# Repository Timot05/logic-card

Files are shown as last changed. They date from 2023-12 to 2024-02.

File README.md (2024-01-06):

# A kit to learn about logic gates

*written in `ato`*

The enclosure contains a programmable microcontroller, two buttons and an LED. Cards can be plugged on top of the enclosure. They turn on the device and program the buttons to act in the same way described by the card placed on the enclosure.

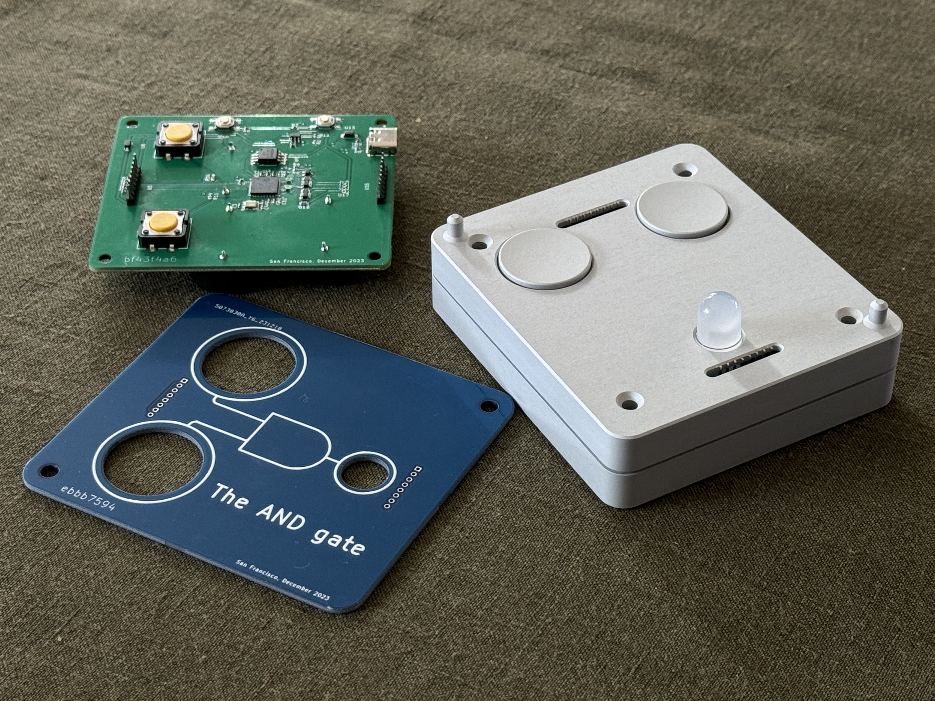
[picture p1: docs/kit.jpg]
gates


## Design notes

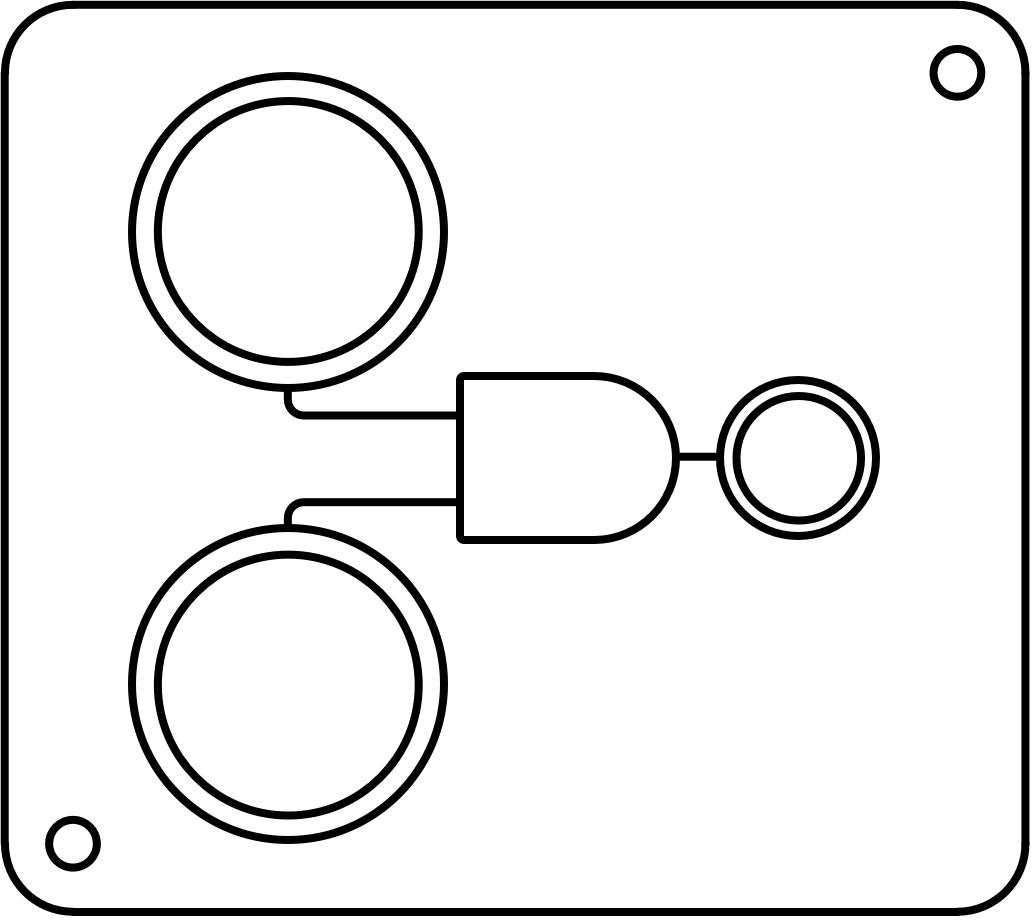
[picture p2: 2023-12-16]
mech/and_gate.png

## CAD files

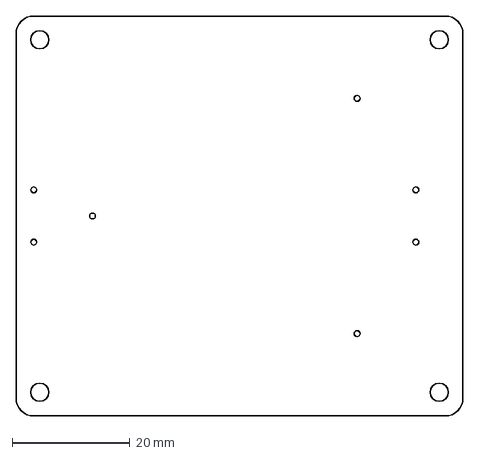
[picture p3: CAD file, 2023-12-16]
mech/main_outline.dxf
76.0 x 68.0 mm

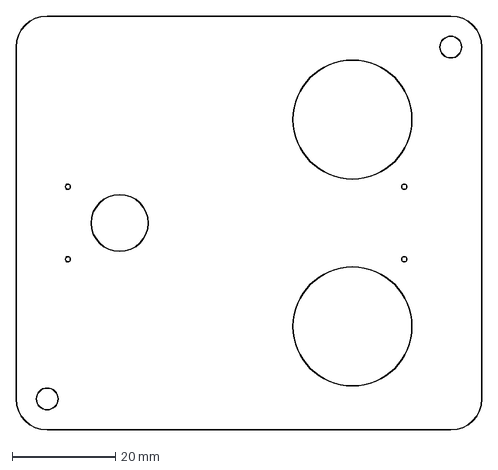
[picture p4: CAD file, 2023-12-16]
mech/card_outline.dxf
90.0 x 80.0 mm

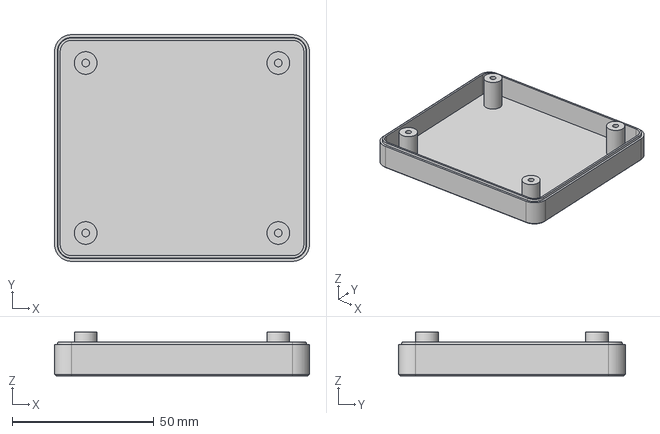
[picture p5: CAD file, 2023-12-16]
mech/bottom_enclosure.step
90.0 x 80.0 x 15.4 mm

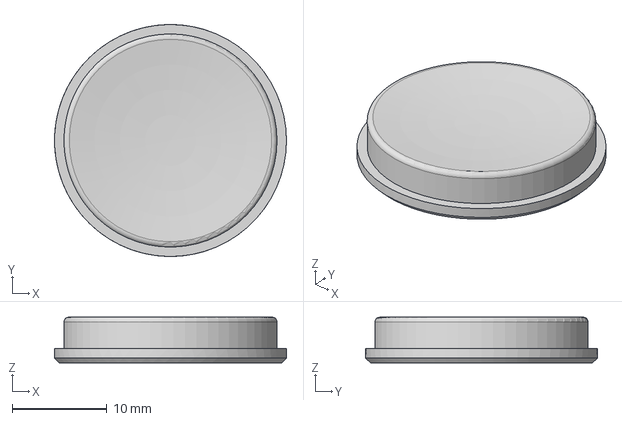
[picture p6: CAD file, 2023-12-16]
mech/button.step
24.5 x 24.5 x 4.82 mm

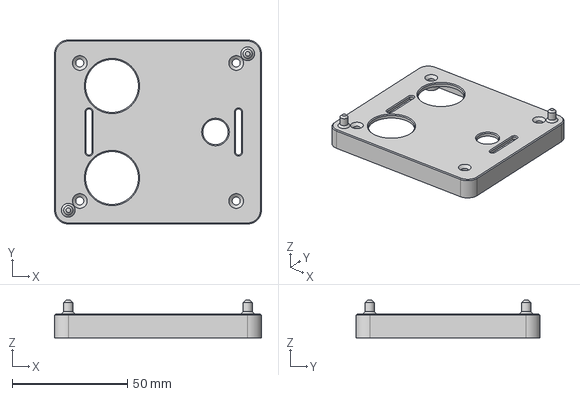
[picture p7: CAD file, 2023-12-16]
mech/top_enclosure.step
90.0 x 80.0 x 16.4 mm

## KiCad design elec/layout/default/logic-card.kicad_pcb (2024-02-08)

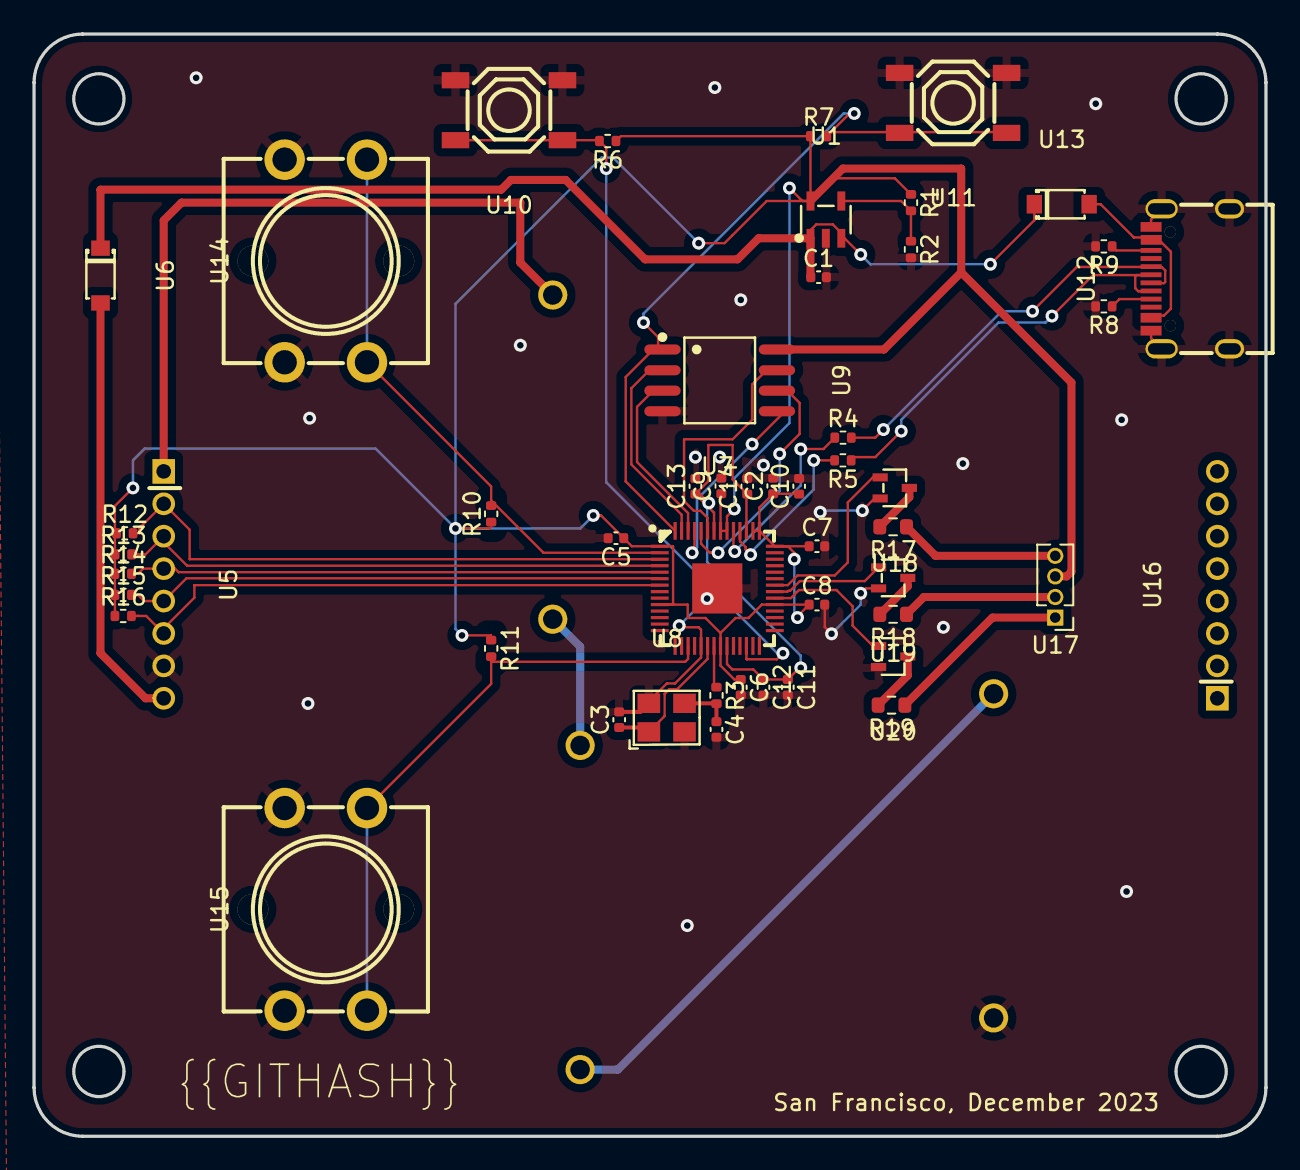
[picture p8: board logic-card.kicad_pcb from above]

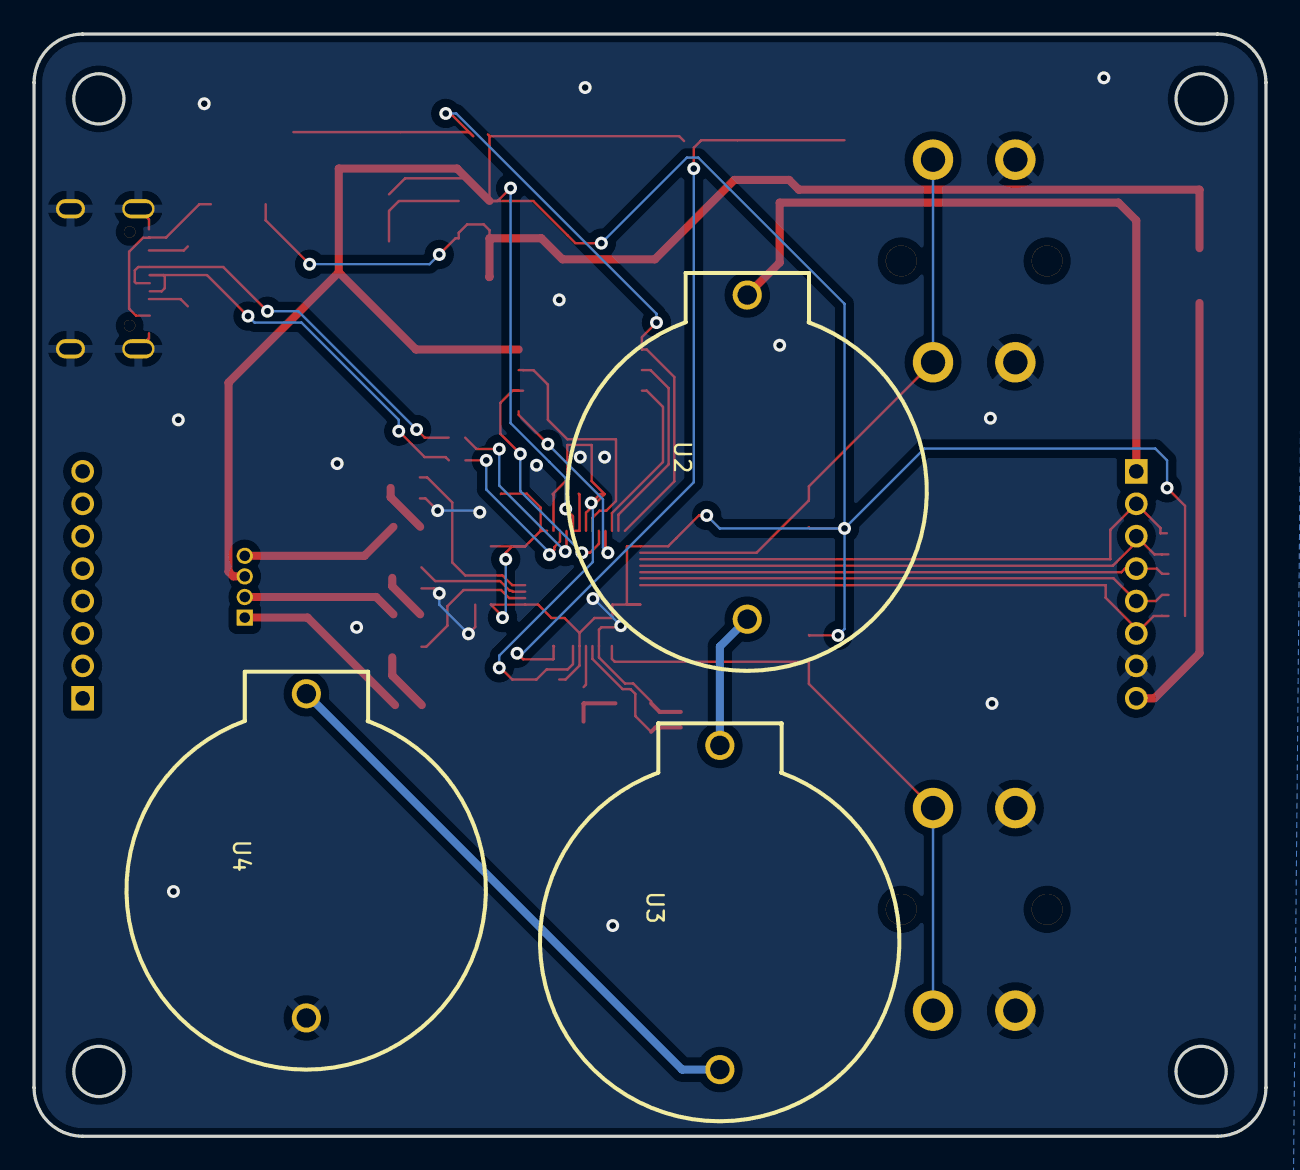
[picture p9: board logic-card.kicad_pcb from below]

Board: 2 copper layers, 76.0 x 68.0 mm, 53 parts (3 on the bottom side), 42 nets.

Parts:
C1, C2, C10, C14: Multilayer Ceramic Capacitors MLCC - SMD/SMT 1uF 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; C0402
C3, C4: Multilayer Ceramic Capacitors MLCC - SMD/SMT 20pF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; C0402
C5, C6, C7, C8, C9, C11, C12, C13: Multilayer Ceramic Capacitors MLCC - SMD/SMT 100n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; C0402
R1: Chip Resistor - Surface Mount 18KOhms ±5% 1/16W 0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; R0402
R2, R6, R7, R12, R13, R14, R15, R16: Chip Resistor - Surface Mount 10KOhms ±5% 1/16W 0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; R0402
R3: Chip Resistor - Surface Mount 1KOhms ±5% 1/16W 04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; R0402
R4, R5: Chip Resistor - Surface Mount 27KOhms ±5% 1/16W 0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; R0402
R8, R9: Chip Resistor - Surface Mount 4.7KOhms ±5% 1/16W 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; R0402
R10, R11: Chip Resistor - Surface Mount 11KOhms ±5% 1/16W 0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; R0402
R17: Chip Resistor - Surface Mount 1.5KOhms ±5% 1/10W 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; R0603
R18, R19: Chip Resistor - Surface Mount 100Ohms ±5% 1/10W 0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; R0603
U1: SOT-23-5_L3.0-W1.7-P0.95-LS2.8-BL
U2, U3, U4: BAT-TH_BS-02-A1AJ010
U5, U16: HDR-TH_8P-P2.00-V-M
U6, U13: SOD-123_L2.8-W1.8-LS3.7-RD
U7: LQFN-56_L7.0-W7.0-P0.4-EP
U8: OSC-SMD_4P-L3.2-W2.5-BL
U9: SOIC-8_L5.3-W5.3-P1.27-LS8.0-BL
U10, U11: SW-SMD_4P-L5.1-W5.1-P3.70-LS6.5-TL-2
U12: USB-C-SMD_KH-TYPE-C-16P
U14, U15: SW-TH_4P-L12.0-W12.0-P5.00-LS12.5-EH
U17: PinHeader_1x04_P1.27mm_Vertical
U18, U19, U20: SOT-323-3_L2.0-W1.3-P1.30-LS2.1-BR

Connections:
CC1: R8.1, U12.A5
CC2: R9.1, U12.B5
b_sink: R19.2, U20.3
cs: R7.2, U7.56, U9.1, U11.1, U11.2
dm: R5.1, U12.A7, U12.B7
dp: R4.2, U12.A6, U12.B6
g_sink: R18.2, U19.3
gnd: C1.2, C2.2, C3.2, C4.2, C5.2, C6.2, C7.2, C8.2, C9.2, C10.2, C11.2, C12.2, C13.2, C14.2, R2.2, R8.2, R9.2, U1.2, U4.1, U5.7, U7.19, U7.57, U8.2, U8.4, U9.4, U10.3, U10.4, U11.3, U11.4, U12.1, U12.2, U12.3, U12.4, U12.A1, U12.A12, U12.B1, U12.B12, U14.3, U14.4, U15.3, U15.4, U18.2, U19.2, U20.2
gnd-1: U2.1, U3.2
gnd-2: U3.1, U4.2
gpio0: R10.2, U7.2, U14.1, U14.2
gpio1: R12.2, U5.2, U7.3
gpio2: R13.2, U5.3, U7.4
gpio3: R14.2, U5.4, U7.5
gpio4: R15.2, U5.5, U7.6
gpio5: R16.2, U5.6, U7.7
gpio14: R11.2, U7.17, U15.1, U15.2
gpio22: U7.34, U20.1
gpio23: U7.35, U19.1
gpio24: U7.36, U18.1
io: R1.2, R2.1, U1.4
io0: U7.53, U9.5
io1: U7.55, U9.2
io2: U7.54, U9.3
io3: U7.51, U9.7
out: U5.8, U6.2
p1: R17.1, U17.4
p1-1: R18.1, U17.2
p1-2: R19.1, U17.1
r_sink: R17.2, U18.3
run: R6.2, U7.26, U10.1, U10.2
sck: U7.52, U9.6
usb_dm: R5.2, U7.46
usb_dp: R4.1, U7.47
vcc: C1.1, U1.1, U1.3, U6.1, U13.1
vcc-1: C2.1, C5.1, C6.1, C7.1, C8.1, C9.1, C10.1, R1.1, R6.1, R7.1, R10.1, R11.1, R12.1, R13.1, R14.1, R15.1, R16.1, U1.5, U7.1, U7.10, U7.22, U7.33, U7.42, U7.43, U7.44, U7.48, U7.49, U9.8, U17.3
vcc-2: U2.2, U5.1
vcc-3: C11.1, C12.1, C13.1, C14.1, U7.23, U7.45, U7.50
vcc-4: C3.1, U7.20, U8.1
vcc-5: C4.1, R3.2, U8.3
vcc-6: U12.A4, U12.A9, U12.B4, U12.B9, U13.2
xout: R3.1, U7.21

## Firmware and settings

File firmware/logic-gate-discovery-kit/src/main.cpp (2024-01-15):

#include <Arduino.h>

#define RED_LED_PIN 24
#define GREEN_LED_PIN 23
#define BLUE_LED_PIN 22

#define WIRE_PIN 1
#define NOT_PIN 2
#define OR_PIN 3
#define AND_PIN 4
#define XOR_PIN 5

#define BUTTON_PIN_1 0
#define BUTTON_PIN_2 14

// states
#define LATCH_STATE     0b11011
#define WIRE_STATE      0b11110
#define NOT_STATE       0b11101
#define OR_STATE        0b11111
#define AND_STATE       0b10111
#define XOR_STATE       0b01111

bool wire_logic(bool button_state) {
    return button_state;
}

bool not_logic(bool button_state) {
    return !button_state;
}

bool or_logic(bool button_1_state, bool button_2_state) {
    return button_1_state || button_2_state;
}

bool and_logic(bool button_1_state, bool button_2_state) {
    return button_1_state && button_2_state;
}

bool xor_logic(bool button_1_state, bool button_2_state) {
    return button_1_state ^ button_2_state;
}

void turn_red() {
    digitalWrite(RED_LED_PIN, HIGH);
    digitalWrite(GREEN_LED_PIN, LOW);
    digitalWrite(BLUE_LED_PIN, LOW);
}

void turn_green() {
    digitalWrite(RED_LED_PIN, LOW);
    analogWrite(GREEN_LED_PIN, 40);
    digitalWrite(BLUE_LED_PIN, LOW);
}

void turn_blue() {
    digitalWrite(RED_LED_PIN, LOW);
    digitalWrite(GREEN_LED_PIN, LOW);
    digitalWrite(BLUE_LED_PIN, HIGH);
}

void turn_purple() {
    analogWrite(RED_LED_PIN, 40);
    digitalWrite(GREEN_LED_PIN, LOW);
    analogWrite(BLUE_LED_PIN, 100);
}

void turn_yellow() {
    digitalWrite(RED_LED_PIN, 80);
    digitalWrite(GREEN_LED_PIN, 50);
    digitalWrite(BLUE_LED_PIN, 0);
}

void turn_white() {
    analogWrite(RED_LED_PIN, 20);
    analogWrite(GREEN_LED_PIN, 15);
    analogWrite(BLUE_LED_PIN, 30);
}

void turn_off() {
    digitalWrite(RED_LED_PIN, LOW);
    digitalWrite(GREEN_LED_PIN, LOW);
    digitalWrite(BLUE_LED_PIN, LOW);
}

void setup() {
    pinMode(WIRE_PIN, INPUT);
    pinMode(NOT_PIN, INPUT);
    pinMode(OR_PIN, INPUT);
    pinMode(AND_PIN, INPUT);
    pinMode(XOR_PIN, INPUT);

    pinMode(BUTTON_PIN_1, INPUT);
    pinMode(BUTTON_PIN_2, INPUT);

    pinMode(RED_LED_PIN, OUTPUT);
    pinMode(GREEN_LED_PIN, OUTPUT);
    pinMode(BLUE_LED_PIN, OUTPUT);

    Serial.begin(9600);
}

void loop() {
    bool wire_state = false;
    bool not_state = false;
    bool or_state = false;
    bool and_state = false;
    bool xor_state = false;

    bool button_1_state = false;
    bool button_2_state = false;

    wire_state = digitalRead(WIRE_PIN);
    not_state = digitalRead(NOT_PIN);
    or_state = digitalRead(OR_PIN);
    and_state = digitalRead(AND_PIN);
    xor_state = digitalRead(XOR_PIN);

    button_1_state = !digitalRead(BUTTON_PIN_1);
    button_2_state = !digitalRead(BUTTON_PIN_2);

    int bit_state = (xor_state << 4) | (and_state << 3) | (or_state << 2) | (not_state << 1) | wire_state;

    Serial.println(bit_state, BIN);

    switch(bit_state) {
        case LATCH_STATE:
            turn_green();
            break;
        case WIRE_STATE:
            if (wire_logic(button_2_state)) {
                turn_white();
            }
            else {
                turn_off();
            }
            break;
        case NOT_STATE:
            if (not_logic(button_2_state)) {
                turn_green();
            }
            else{
                turn_off();
            }
            break;
        case OR_STATE:
            if (or_logic(button_1_state, button_2_state)) {
                turn_purple();
            }
            else {
                turn_off();
            }
            break;
        case AND_STATE:
            if (and_logic(button_1_state, button_2_state)) {
                turn_blue();
            }
            else {
                turn_off();
            }
            break;
        case XOR_STATE:
            if (xor_logic(button_1_state, button_2_state)) {
                turn_yellow();
            }
            else {
                turn_off();
            }
            break;
        default:
            turn_green();
            break;
    }
    delay(50);
}

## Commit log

2023-11-14 add layout, lib, ato code
    [atopile-project-template.kicad_pcb, atopile-project-template.kicad_sch]
2023-11-14 add kicad lib and chip in layout
    [atopile-project-template.kicad_pcb]
2023-11-14 move kicad layout around
    [atopile-project-template.kicad_pcb, atopile-project-template.kicad_sch]
2023-11-15 added a few more comments, added a cap so we can show connections, modified kicad project lib path as it was broken
    [atopile-project-template.kicad_pcb]
2023-11-15 add mech folder and git hash
    [atopile-project-template.kicad_pcb, template_outline.dxf]
2023-11-26 remove the old layout
    [atopile-project-template.kicad_pcb]
2023-12-05 Initial commit for testing123
    [testing123.kicad_pcb, testing123.kicad_sch]
2023-12-08 Rename all the things that became testing123
    [template123.kicad_pcb, template123.kicad_sch]
2023-12-09 Initial commit for logic-card
    [logic-card.kicad_pcb, logic-card.kicad_sch]
2023-12-10 update the rp2040 kit
    [logic-card.kicad_pcb, main_outline.dxf]
2023-12-10 add some buttons
2023-12-10 last footprint
2023-12-11 finished up
    [logic-card.kicad_pcb]
2023-12-11 stabil junge
    [bottom_enclosure.step, button.step, logic-card.kicad_pcb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]
2023-12-16 update gitignore
    [logic-card.kicad_pcb]
2023-12-16 update the layout
    [logic-card.kicad_pcb]
2023-12-16 add a few layouts
    [card-and.kicad_pcb, card-and.kicad_sch, card-or.kicad_pcb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]
2023-12-16 switch to coin cells
    [logic-card.kicad_pcb]
2023-12-16 add button outlines
2024-01-01 fix the led pins
    [logic-card.kicad_pcb]
2024-01-01 fix oscillator
    [logic-card.kicad_pcb]
2024-01-10 Update CI to use atopile-kicad contiainer
2024-01-15 add modes, fix for broken card
    [main.cpp]
2024-02-05 Fix fp-lib-table and UUIDs
    [logic-card.kicad_pcb]
2024-02-08 fix the build
    [logic-card.kicad_pcb]
2024-02-08 add new layout
    [card-and.kicad_pcb, card-and.kicad_sch, card-or.kicad_pcb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]
